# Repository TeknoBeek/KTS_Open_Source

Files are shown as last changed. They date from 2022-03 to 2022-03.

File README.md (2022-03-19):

# KTS_Open_Source

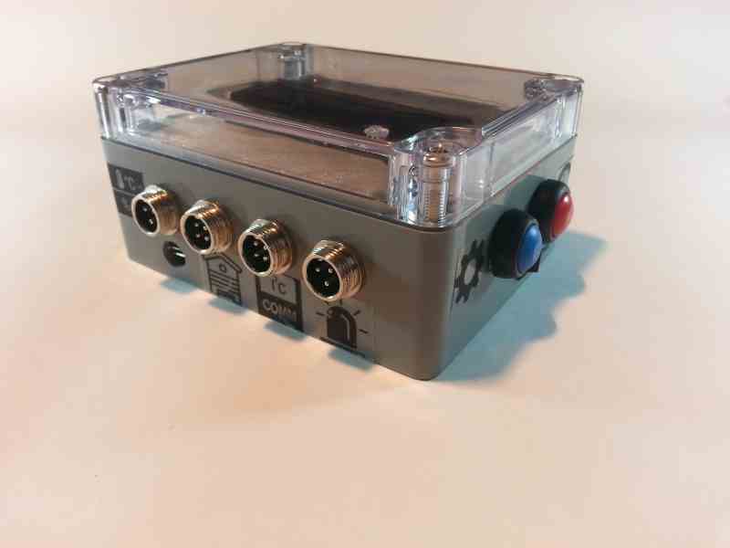
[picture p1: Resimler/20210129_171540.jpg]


# Kovan Takip Sistemi Açık Kaynak Dosyaları

KTS donanım olarak açık kaynak olarak paylaşılmıştır.

Yazılım kısmında ise cihazın TEMEL ÖZELLİKLERİNİ kullanabileceğiniz bir bedava bir sürüm (firmware) bulunmaktadır.

Profesyonel ve TAM SÜRÜME ileride küçük bir ücret mukabili geçilebilecektir.

KTS piyasada hazır olarak kolayca bulunabilecek modüller kullanılarak geliştirildi. 

Yani sonuçta AMATÖR bir cihaz olacak.

Bu yüzden de TR'de ve dünyada muhtemelen en ucuza mal edilebilecek bir veri kaydedici olacaktır.

AMATÖR bir cihaz olmasına rağmen kullanılacak alan için profesyonele yakın bir çözüm sunmaktadır. 

Ve 5 yıla aşkın saha kullanımında da gayet yeterli olduğunu kanıtlamıştır.

Bu cihazın amatör şartlar dahilinde geliştirildiğini unutmamanızı tavsiye ederim.

Bu yüzden doğabilecek olumsuzluklar hakkında hiç bir şekilde sorumluluk almam. 

Yalnız cihazın ARICILIK ile ilgili bölümündeki tasarım, 20 seneyi aşkın arıcılık geçmişim sayesinde olmuştur.

Hangi sensörlerin kullanılması gerekliliği, nerede kullanılacağı,

nelerin takip edileceği, verilerin nasıl analiz edileceği vb. konular bu sebeple yabancısı olmadığım konular.

6 seneyi aşkın bir süre içinde gelişe gelişe cihaz bugünkü haline evrildi.

KTS nedir tanıtım PDF'inde de bahsedildiği gibi bu cihaz aslında bir veri toplayıcı. 

Arıcılık sektöründe kullanılabileceği gibi SERACILIK, SULAMA, KÜMES OTOMASYONU, EV OTOMASYONU, HAVA İSTASYONU vb. 

bir çok alanda da kullanılabilecek şekilde, modüler bir biçimde yapıldı.

Farklı bir alanda kullanmak için ilgili modülü konnektörden ekleyip, o modulün

yazılımını yüklemek yeterli olacak.

Bundan sonraki tüm yazılımlar bu donanım ile uyumlu olacak.

İlerleyen zamanlarda www.akıllıkovan.com veya GitHub üzerinden bu yazılımlara ulaşmak mümkün olacak.

# NASIL BİR YOL İZLENECEK

Öncelikle www.akıllıkovan.com web sitesi dökümantasyon için kullanılacak.

GitHub adresinde de yine yapım bilgilerini içeren PDF dosyaları, PCB dosyaları (Gerber ve BRD) , ve YAZILIM Firmware bulunacak.

Youtube kanalında ise hem tanıtım videoları hem de yapım aşamalarını gösteren kısa ve uzun videolar bulanacak. Bu sebeple kanala abone olmanızı tavsiye ederim. https://www.youtube.com/c/TeknoBeek

------------------------------------------------------------------------------------

# KİMLER YAPABİLİR ?

Temel seviyede elektronik bilgisi olan herkes yapabilir.

Bilinmesi gereken konular;

Kart dizilimi ve lehimleme, (kablo lehimleme - bağlama vb. dahil)

PCB'yi kendi yapacaksa ev yapımı PCB bilgisine haiz olmak,

Mikroişlemciye yazılım atmak.

Montaj konusundaki delme, yapıştırma vb. el işçiliği.

Arıcılar yarı marangoz olduğu için en kolay kısım burası olacaktır.

Kendiniz yapamadığınız takdirde meslek lisesinde bulunan bir çocuk bile muhtemelen bunları yapabilecektir.

-------------------------------------------------------------------------------------

# PARÇALAR NEREDEN TEMİN EDİLECEK ?

Elektronik parçaların hepsi ister yurtiçinden isten yurtdışından kolaylıkla bulunabilecek şekilde tasarlandı.

Türkiye'de online alışveriş yapılabilen büyük firmaların birisinden hepsi temin edilebilir.

Elektronik kısmına ait liste sitede bulunmaktadır.

Kutu seçimi isteğe bağlı olmakla beraber açık kaynaktaki kutu TR'deki bir firmadan temin edilebilir.

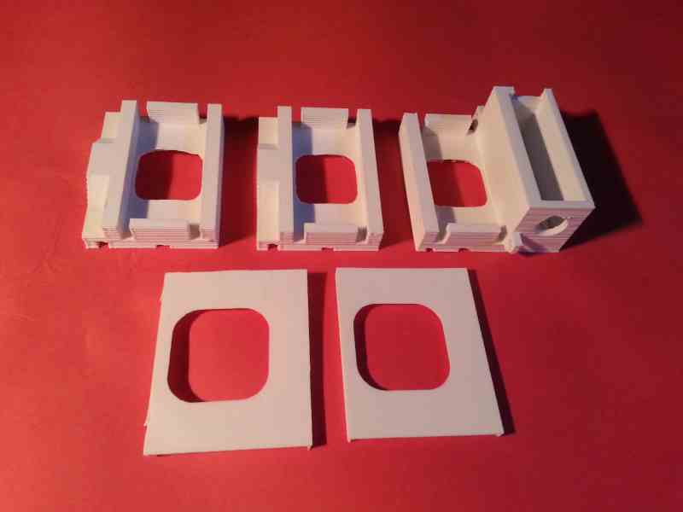
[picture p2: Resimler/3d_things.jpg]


Plastik parçalar özel üretim olduğu için muhtemelen bu projenin en zor bulunacak bölümünü oluşturuyor.

3D çizim dosyaları thingiverse hesabımdan indirilip 3D yazıcıda yazdırılabilir.

Bu hesapta da 3D klasöründe STL dosyaları bulunmaktadır.

Baskı almak için Türkiye'de 3D baskı yapan firmalar var.

Bu konuda ben de yardımcı olmaya çalışırım.

PCB konusunda kendi yapabilecek veya birine yaptırabilecek kimseler için çizim dosyaları bu hesapta bulunacaktır.

Profesyonel firma üretimi olan PCB'ler (Çin) elimde fazla bulunduğu takdirde

bu konuda da yardımcı olabilirim.

Plastik Altlık kullanılacak ise kullanılacak altlığın modeli sitede yazmaktadır.

Tüm 3D plastik parçalar bu model altlığa göredir.

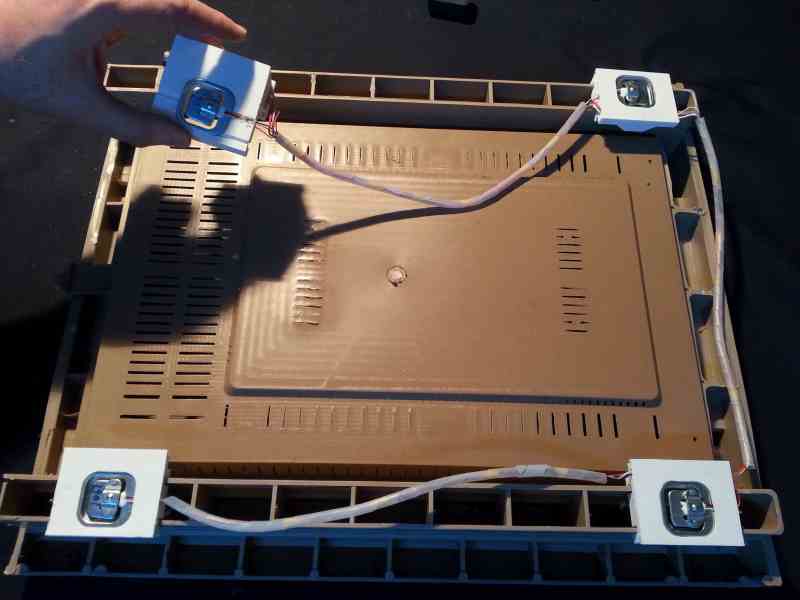
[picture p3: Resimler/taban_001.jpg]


Altlık kullanılmayıp onun yerine bir platform kullanılacaksa bununla ilgili de 3D çizimler ayrıca verilmiştir.

Piyasadan hazır dijital kantar kullanımı ile ilgili bilgi notu yakında paylaşılacaktır.

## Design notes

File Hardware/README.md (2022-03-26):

# KTS PCB 

Güncelleme: 
V_002 yüklendi. SE-222 Kodlu kutuya uygun olarak dizayn edildi. 
V_002 klasöründe gerber dosyaları mevcut. Testleri yapıldı
-------------------------------------------------------------
Önemli not ! 

Donanım ve yazılım konusunda formal bir eğitimim yoktur. 
Hobi amaçlı ve amatör ruhla geliştirilmeye çalışılmıştır. 
Bunun göz önünde tutulması rica olunur. 

Versiyon1 evde de imal edilebilmesi amacıyla ağırlıklı olarak tek yüzlü olarak tasarlandı. 
Sadece birkaç köprü kablo ile çalıştırılabilmektedir. 
Ütü, aseton vb. ev tipi tekniklerle imal edilebilir. 
Ev tipi üretim konusunda yönlendirme yapabilirim. 

Çin'den veya TR'deki bir firma üzerinden üretim yaptırmak isterseniz 
gerekli gerber dosyaları da buradadır. 
Ben bu dosyalar ile Çin üzerinden bir firma ile PCB yaptırdım. 
Elimde fazla olduğu takdirde PCB temini konusunda da yardımcı olabilirim. 

Bu dizindeki BOM dosyası Eagle CAM'in kendi çıkardığı dosyadır. 
Daha detaylı bilgiye PDF dizinindeki malzemeler dosyasından ulaşabilirsiniz.

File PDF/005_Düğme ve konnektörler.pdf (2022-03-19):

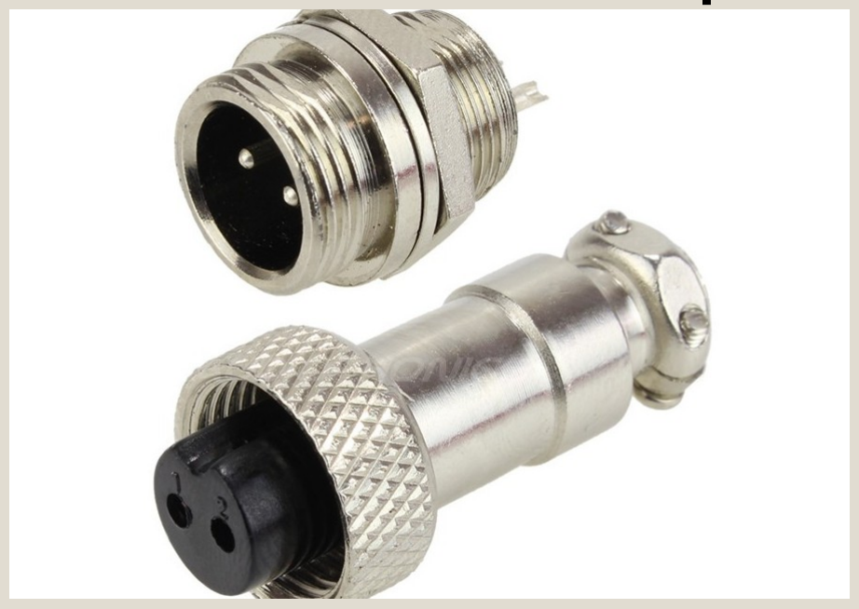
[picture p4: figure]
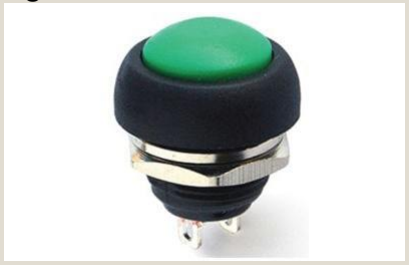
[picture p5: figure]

Konnektör olarak Gx_12 / 3 ve 4 pinli kullanıldı. Düğme olarak M12 boyutlu istenilen tip bir düğme kullanılabilir.

## Düğme ve Konnektörler

### 4 pinli bağlantı için ayak

numaraları bu şekilde
olmalı.

### 3 pinli bağlantı için ayak

numaraları bu şekilde
olmalı.

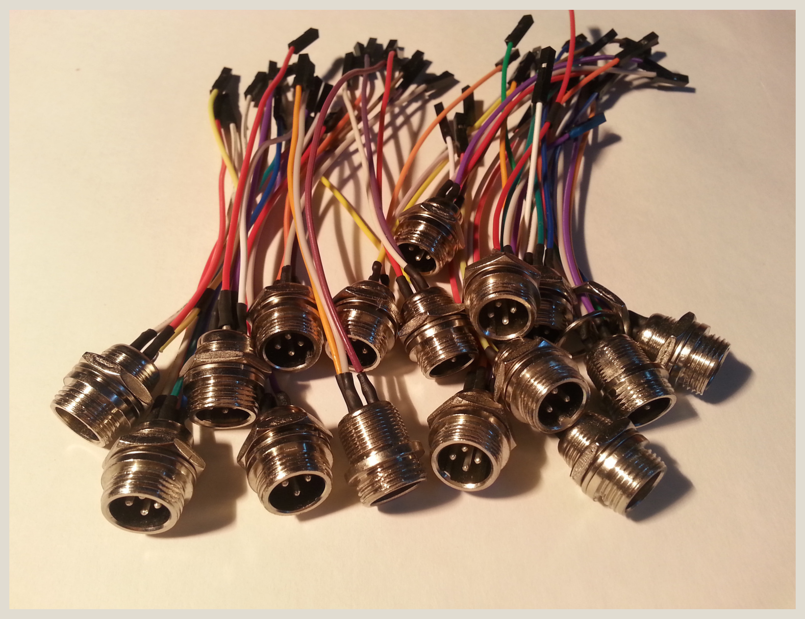
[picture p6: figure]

Kablo olarak dişi jumper
kablosu kullanılıyor.
Dişi - Dişi bir jumper
kablosunu ortadan
keserek kullanıyoruz.

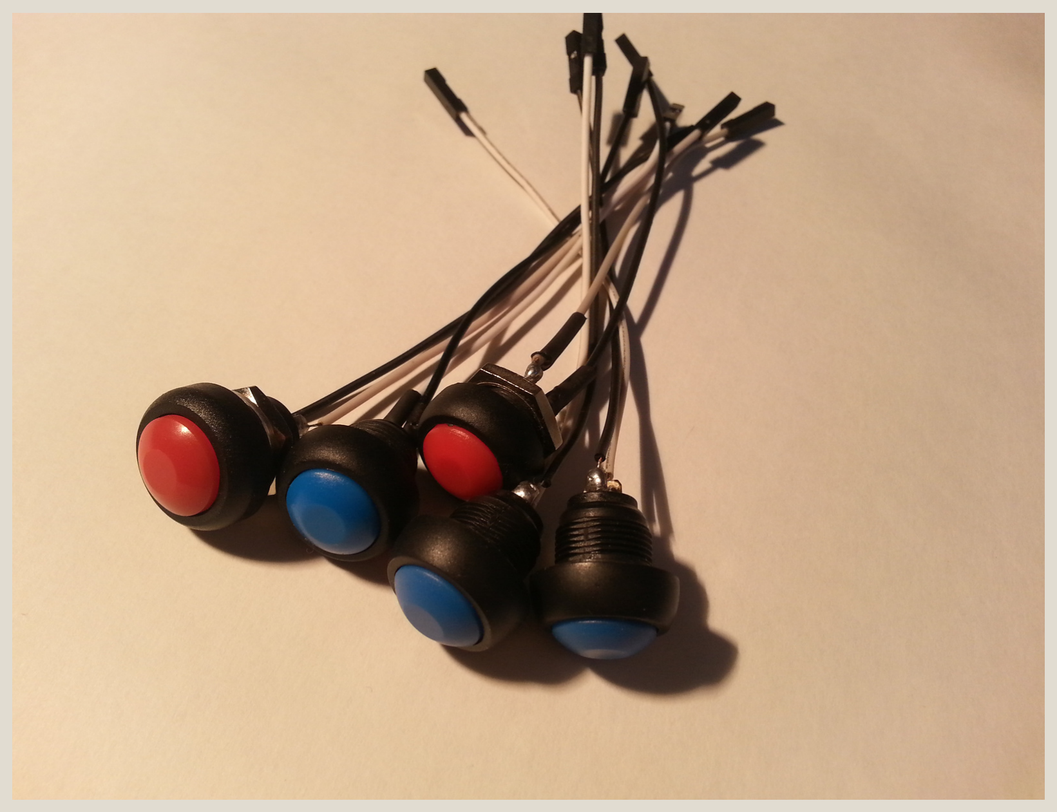
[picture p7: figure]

Vcc bağlantısı için
genelde turuncu veya
kırmızıyı, Gnd için ise
beyaz veya ona yakın
açık renkler tercih
edildi.

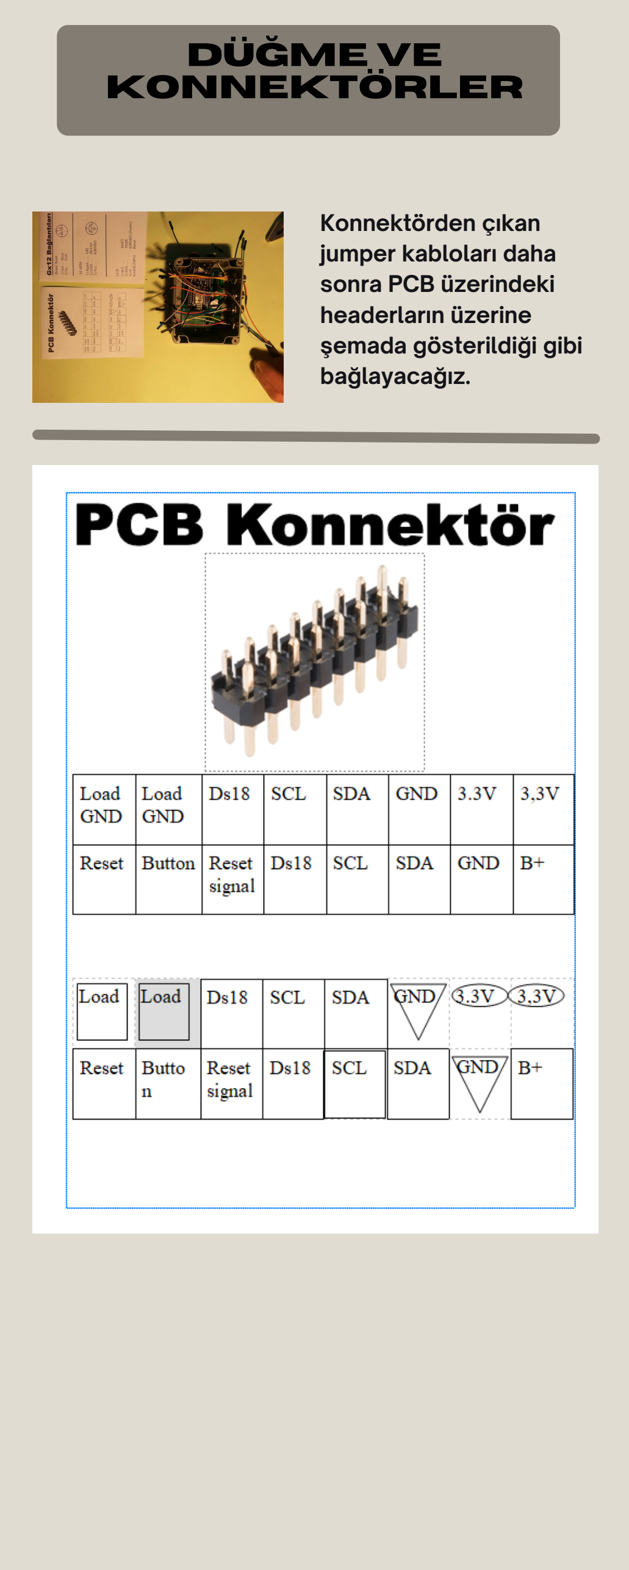
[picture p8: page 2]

Konnektörden çıkan
jumper kabloları daha
sonra PCB üzerindeki
headerların üzerine
şemada gösterildiği gibi
bağlayacağız.

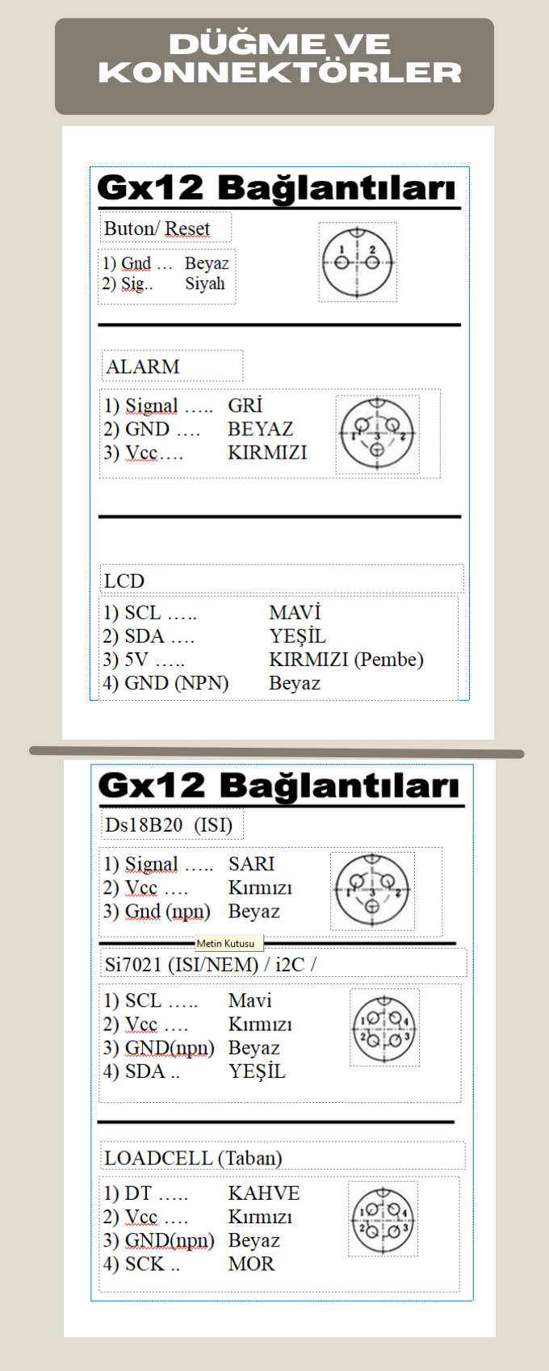
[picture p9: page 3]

## NOTLAR

1) Renkler konusunda dikkat edilecek husus; Vcc için kırmızı veya ona yakın renklerin, GND için beyaz veya yakın renklerin tercihi hata ayıklamada fayda sağlar. Onun dışında elinizde bulunan jumper kablolarının rengine göre bağlantıyı dilediğiniz gibi yapabilirsiniz. Şemada yazan renklere bağlı kalmak zorunda değilsiniz.
2) Hem konnektör hem de button ayaklarında ısı ile daralan makaron kullanılması tavsiye olunur.
3) Kutu tercihlerinize göre Gx12 yerine Gx16 konnektör veya farklı tipte düğme tercih edebilirsiniz.
Bu durumda haliyle sitedeki kutu şablonlarından istifade edemezsiniz.
4) Dişi jumper kablolar daha sonra PCB montaj bölümünde anlatılacak olan PCB üzerindeki header'a bağlanacak. Bağlantı şeması da o bölümde detaylı bir anlatımla verilecektir.
5) Cihazı full olarak kullanmak istediğiniz takdirde
3 adet erkek 4 pinli
2 adet erkek 3 pinli
3 adet dişi 4 pinli
2 adet dişi 3 pinli Gx12 konnektöre ihtiyacınız olacak.

Button olarak 2 adet push button switch yeterli.

Bu listeler başka bir bölümde (malzeme listesi) detaylı olarak ele alınacaktır.

6) Gx12 konnektörlerin hem dişi, hem erkeklerinde pinleri belirten sayılar vardır. Zaten bağlantılar bu rakamlara göre yapılacaktır.
7) LCD kablosu için birşey yapılması gerekmiyor.
Dişi - dişi 4 adet jumper kablosu yeterli. LCD'ye gelen tarafına dilerseniz bir makaron takılabilir.

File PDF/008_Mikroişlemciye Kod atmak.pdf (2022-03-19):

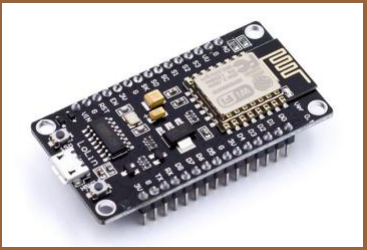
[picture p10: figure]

Piyasada iki çeşit NodeMcu var.
Bir tanesi USB için CP2102 kullanıyor. Diğeri ise Ch340.
Her ikisi için de PC'ye driver indirmeniz gerekiyor.

CP2102 chip için driver adresi: https://www.silabs.com/developers/usb-touart-bridge-vcp-drivers (https://www.silabs.com/developers/usb-to-uart-bridge-vcp-drivers)

Ch340 için driver:
https://learn.sparkfun.com/tutorials/how-to-install-ch340-drivers/all (https://learn.sparkfun.com/tutorials/how-to-install-ch340-drivers/all)

### Mikroişlemciye YAZILIM YÜKLEME

ANA İŞLEMCİ
--------------------------------NodeMCU LoLin
ESP8266 Geliştirme
Kartı - USB Chip (https://www.motorobit.com/urun/nodemcu-lolin-esp8266-gelistirme-karti-usb-chip)

Driverlar işletim sisteminize sorunsuz bir şekilde tanıtıldıktan sonra artık USB kablosu ile PC'nizin USB'sine mikroişlemcimizi bağlayabilir ve yazılım atabiliriz.
Yazılım atabilmek için bir programa ihtiyaç var. Piyasada çok program olsa da benim tercihim şu:
Win32 (https://github.com/nodemcu/nodemcu-flasher/raw/master/Win32/Release/ESP8266Flasher.exe)
Win64 (https://github.com/nodemcu/nodemcu-flasher/raw/master/Win64/Release/ESP8266Flasher.exe)

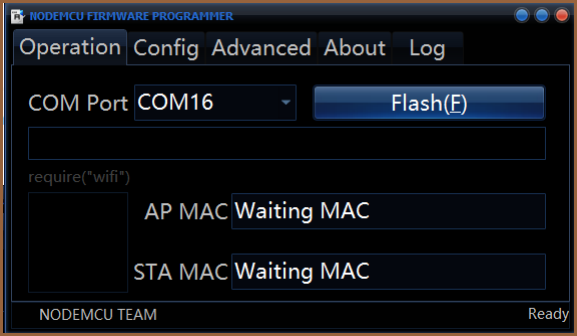
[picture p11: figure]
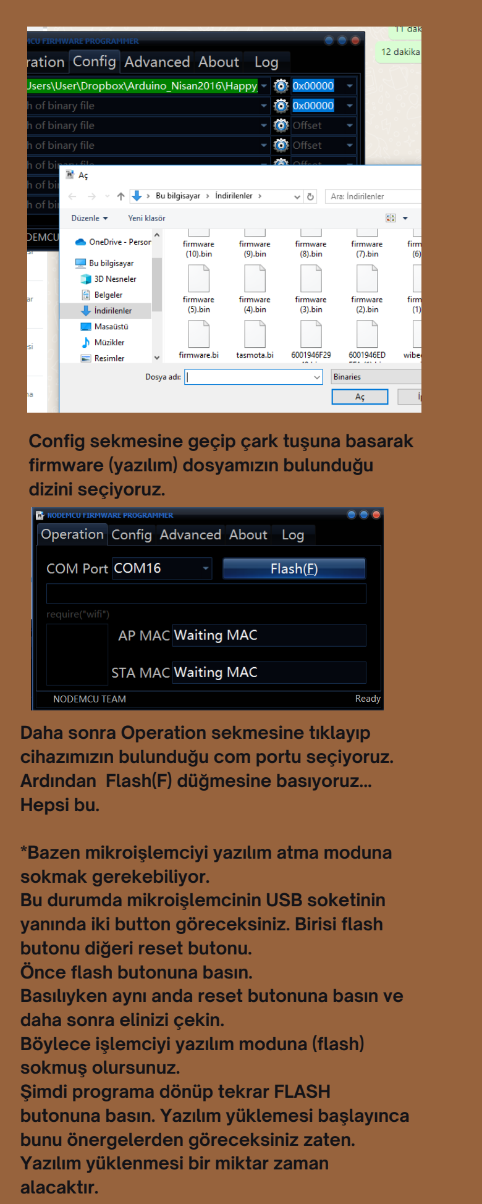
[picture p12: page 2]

Config sekmesine geçip çark tuşuna basarak firmware (yazılım) dosyamızın bulunduğu dizini seçiyoruz.

Daha sonra Operation sekmesine tıklayıp cihazımızın bulunduğu com portu seçiyoruz. Ardından Flash(F) düğmesine basıyoruz... Hepsi bu.

*Bazen mikroişlemciyi yazılım atma moduna sokmak gerekebiliyor.
Bu durumda mikroişlemcinin USB soketinin yanında iki button göreceksiniz. Birisi flash butonu diğeri reset butonu.
Önce flash butonuna basın.
Basılıyken aynı anda reset butonuna basın ve daha sonra elinizi çekin.
Böylece işlemciyi yazılım moduna (flash) sokmuş olursunuz.
Şimdi programa dönüp tekrar FLASH butonuna basın. Yazılım yüklemesi başlayınca bunu önergelerden göreceksiniz zaten. Yazılım yüklenmesi bir miktar zaman alacaktır.

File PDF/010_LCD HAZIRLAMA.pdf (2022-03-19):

### LCD HAZIRLAMA

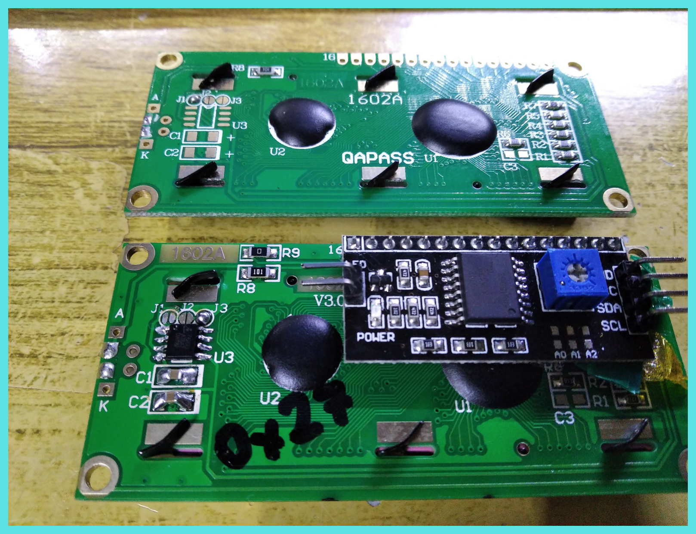
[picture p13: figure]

Bu ekranlar normalde
5V olduğu için bunu
3.3V'a çevirmemiz
gerekiyor.

Bunun için 2 adet 10uf
kapasitör (SMD) ve bir
adet L7660 SMD DC DC
çevirici kullanmak
gerekiyor.

En son mevcut jumper
lehimini söküp en sağdaki
yeri lehimlemeliyiz.

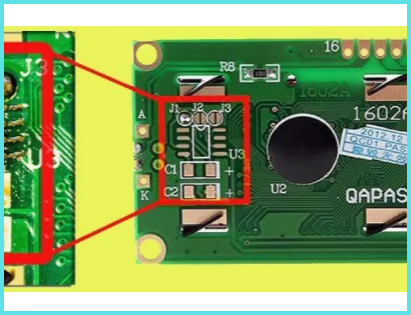
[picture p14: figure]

Detaylı bilgiye buradan (https://www.codrey.com/electronic-circuits/hack-your-16x2-lcd/)
ulaşabilirsiniz...

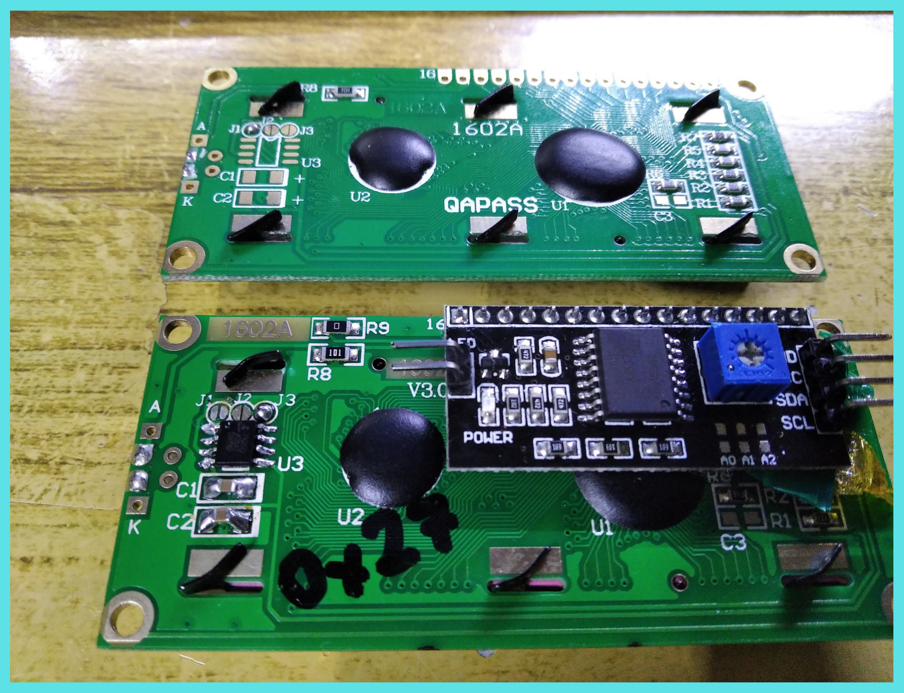
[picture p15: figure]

16x2 Standart bir
ekrana i2c modülü
takıyoruz

Standart bir 5V 16x2 LCD ekranı

### 3.3 V'a çevirmek

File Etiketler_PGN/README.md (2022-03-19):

# Etiketler



Kutu üzerinde kullanılacak etiketler 

ve kutu yapımında kullanılacak şablon -  bağlantı şemaları vb. dökümasyona buradan ulaşabilirsiniz.

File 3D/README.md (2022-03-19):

# 3D Dosyalar



Bu parçalar TR'de satılan bir plastik kovana uyumlu yapılmıştır. 

Başka bir altlık ile uyumsuzluk yaşanması muhtemeldir. 

Plastik altlık yerine düz bir platforma uygulama yapılacaksa bunun için 

https://www.thingiverse.com/search?q=loadcell&type=things&sort=relevant üzerinden bir aratma yapılıp 

size uygun tasarıp bulunup basılabilir. 

Buradaki dosyalar https://www.thingiverse.com/cemoka/designs hesabımda da bulunmaktadır. 

Oradan her zaman daha güncel dosyalara erişmek mümkün olacaktır. 

PetG veya ABS gibi dayanıklı bir malzeme ile baskı tercih edilmelidir.

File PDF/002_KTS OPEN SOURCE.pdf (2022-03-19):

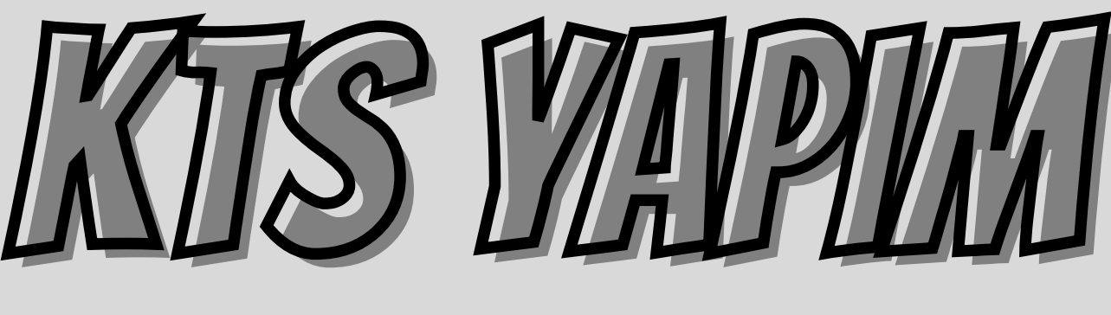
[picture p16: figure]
KTS YAPIM
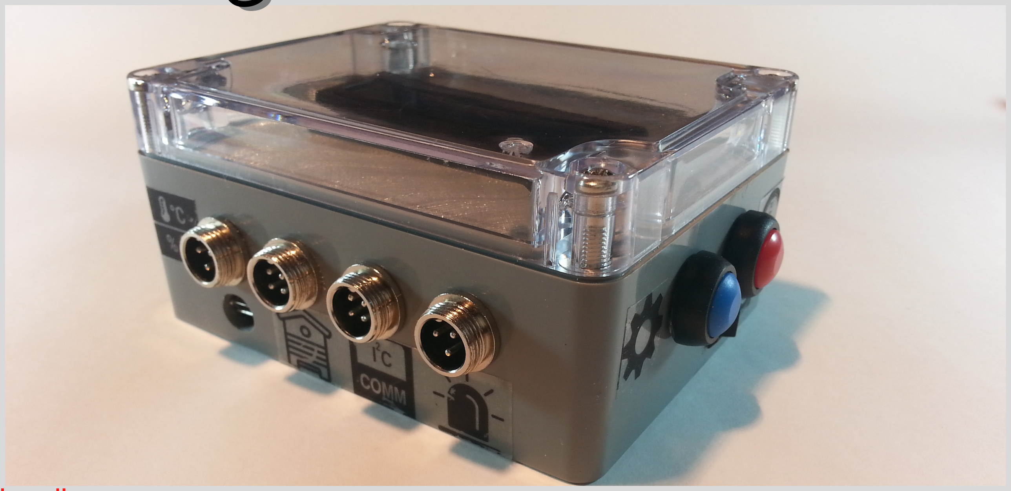
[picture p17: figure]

ÖNSÖZ
KTS donanım olarak açık kaynak paylaşılmıştır.
Yazılım kısmında ise cihazın TEMEL ÖZELLİKLERİNİ kullanabileceğiniz bir bedava bir sürüm (firmware) bulunmaktadır.
Profesyonel ve TAM SÜRÜME ileride küçük bir ücret mukabili geçilebilecektir.

KTS piyasada hazır olarak kolayca bulunabilecek modüller kullanılarak geliştirildi. Yani sonuçta AMATÖR bir cihaz olacak.
Bu yüzden de TR'de ve dünyada muhtemelen en ucuza mal edilebilecek bir veri kaydedici olacaktır.
AMATÖR bir cihaz olmasına rağmen kullanılacak alan için profesyonele yakın bir çözüm sunmaktadır. Ve 5 yıla aşkın saha kullanımında da gayet yeterli olduğunu kanıtlamıştır.

Biraz da proje geliştiricisi bendeniz hakkında konuşayım:
Ben çocukluktan beri elektroniği hobi amaçlı ve amatör düzeyde yapmaktayım. Gerek donanım gerekse yazılım konusunda formal bir eğitimim olmadı.
Bu konuda kendi kendimi yetiştirdim.
Fakat yine de her iki alanda da çok yetersiz olduğum bir gerçek.
Bu cihazın bu şartlar dahilinde geliştirildiğini unutmamanızı tavsiye ederim. Bu yüzden doğabilecek olumsuzluklar hakkında hiç bir şekilde sorumluluk almam. Yalnız cihazın ARICILIK ile ilgili bölümündeki tasarım, 20 seneyi aşkın arıcılık geçmişim sayesinde olmuştur.
Hangi sensörlerin kullanılması gerekliliği, nerede kullanılacağı,
nelerin takip edileceği, verilerin nasıl analiz edileceği vb. konular bu sebeple yabancısı olmadığım konular.
6 seneyi aşkın bir süre içinde gelişe gelişe cihaz bugünkü haline evrildi.

Takip edenlerin bileceği gibi kovan verilerinin takip edilebileceği bir profesyonel cihaz geçen yıllar içinde üretildi.
Ancak firma ile olan anlaşmazlıklar sebebiyle (özellikle fiyat konusunda) cihazı onlara bırakıp o süreçten çekildim ve yine eski kendi cihazıma döndüm.
Yani hazır modüller kullanılarak oluşturulan bir donanım ve yazılım ile bu cihaz hazırlandı.

KTS nedir tanıtım PDF'inde de bahsedildiği gibi bu cihaz aslında bir veri toplayıcı. Arıcılık sektöründe kullanılabileceği gibi SERACILIK, SULAMA, KÜMES OTOMASYONU, EV OTOMASYONU, HAVA İSTASYONU vb. bir çok alanda da kullanılabilecek şekilde, modüler bir biçimde yapıldı.

Farklı bir alanda kullanmak için ilgili modülü konnektörden ekleyip, o modulün yazılımını yüklemek yeterli olacak.

Bundan sonraki tüm yazılımlar bu donanım ile uyumlu olacak.
İlerleyen zamanlarda www.akıllıkovan.com (https://www.xn--akllkovan-wpbc.com/p/kts-nedir.html) veya GitHub (https://github.com/TeknoBeek) hesabı üzerinden bu yazılımlara ulaşmak mümkün olacak.

# AÇIK KAYNAK

NASIL BİR YOL İZLENECEK

Öncelikle www.akıllıkovan.com (https://www.xn--akllkovan-wpbc.com/p/kts-nedir.html) web sitesi dökümantasyon için kullanılacak.

GitHub (https://github.com/TeknoBeek) adresinde de yine yapım bilgilerini içeren PDF dosyaları, PCB dosyaları (Gerber ve BRD) , ve YAZILIM Firmware bulunacak.

Youtube kanalında ise hem tanıtım videoları hem de yapım aşamalarını gösteren kısa ve uzun videolar bulanacak. Bu sebeple kanala abone olmanızı tavsiye ederim. https://www.youtube.com/c/TeknoBeek

---------------------------------------------------------------------------------------------------------------KİMLER YAPABİLİR ?

Temel seviyede elektronik bilgisi olan herkes yapabilir.
Bilinmesi gereken konular;

Kart dizilimi ve lehimleme, (kablo lehimleme - bağlama vb. dahil) PCB'yi kendi yapacaksa ev yapımı PCB bilgisine haiz olmak, Mikroişlemciye yazılım atmak.
Montaj konusundaki delme, yapıştırma vb. el işçiliği.
Arıcılar yarı marangoz olduğu için en kolay kısım burası olacaktır.

Kendiniz yapamadığınız takdirde meslek lisesinde bulunan bir çocuk bile muhtemelen bunları yapabilecektir. ---------------------------------------------------------------------------------------------------------------PARÇALAR NEREDEN TEMİN EDİLECEK ?

Elektronik parçaların hepsi ister yurtiçinden isten yurtdışından kolaylıkla bulunabilecek şekilde tasarlandı.
Türkiye'de online alışveriş yapılabilen büyük firmaların birisinden hepsi temin edilebilir.
Elektronik kısmına ait liste sitede bulunmaktadır.

Yapacağınız cihazda ihtiyacınız olmayacağını düşündüğünüz sensörleri iptal edebilirsiniz. Mesela "Ben sadece ağırlık takip etmek istiyorum" diyen biri ısı ve nem sensörlerini almayabilir. Fakat sensörleri almasanız da kutudaki konnektörlerin tam olmasını tavsiye ederim.
Zira ilerideki farklı kullanım alanları için cihazınız standart donanıma sahip olmuş olur.
Mesela ileride aynı cihazı otomatik sulama veya SERA otomasyonu gibi bir amaçla da kullanabilirsiniz. Zaten konnektör farkı 10 - 15 TL gibi bir tutardır.

Kutu seçimi isteğe bağlı olmakla beraber açık kaynaktaki kutu TR'deki bir firmadan temin edilebilir.

Plastik parçalar özel üretim olduğu için muhtemelen bu projenin en zor bulunacak bölümünü oluşturuyor.
3D çizim dosyaları thingiverse (https://www.thingiverse.com/cemoka/designs) hesabımdan indirilip 3D yazıcıda yazdırılabilir. 3D baskı yapan firmalar var.
Bu konuda ben de yardımcı olmaya çalışırım.

PCB konusunda kendi yapabilecek veya birine yaptırabilecek kimseler için çizim dosyaları gitHub (https://github.com/TeknoBeek) hesabında bulunacaktır.
Profesyonel firma üretimi olan PCB'ler (Çin) elimde fazla bulunduğu takdirde bu konuda da yardımcı olabilirim.

Plastik Altlık kullanılacak ise kullanılacak altlığın modeli önemlidir.
Tüm 3D plastik parçalar bu model altlığa göredir.
Altlık kullanılmayıp onun yerine bir platform kullanılacaksa bununla ilgili de 3D çizimler ayrıca verilmiştir.

Piyasadan hazır dijital kantar kullanımı ile ilgili bilgi notu yakında paylaşılacaktır.

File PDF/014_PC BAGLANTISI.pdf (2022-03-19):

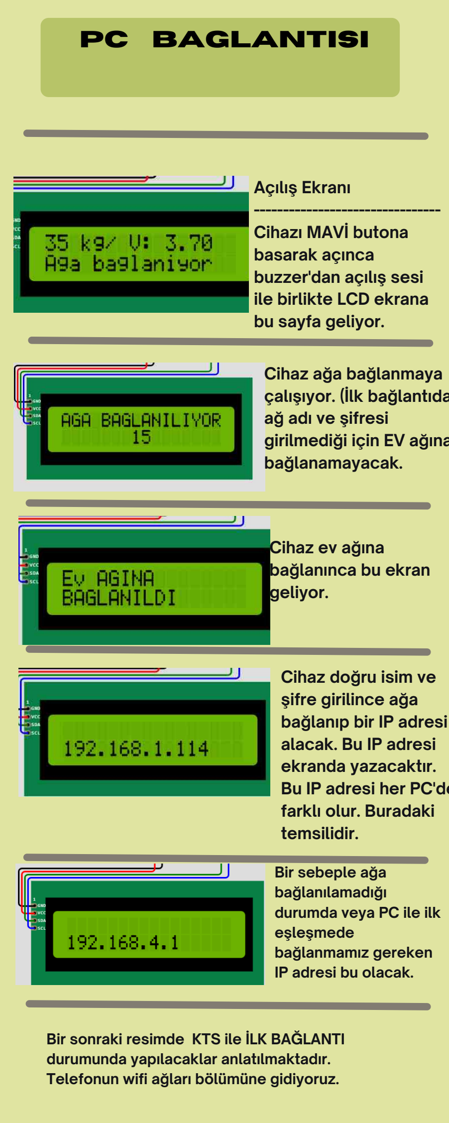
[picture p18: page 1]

Açılış Ekranı
--------------------------------Cihazı MAVİ butona
basarak açınca
buzzer'dan açılış sesi
ile birlikte LCD ekrana
bu sayfa geliyor.

Cihaz ağa bağlanmaya
çalışıyor. (İlk bağlantıda ağ adı ve şifresi
girilmediği için EV ağına
bağlanamayacak.

Cihaz ev ağına
bağlanınca bu ekran
geliyor.

Cihaz doğru isim ve
şifre girilince ağa
bağlanıp bir IP adresi
alacak. Bu IP adresi
ekranda yazacaktır.
Bu IP adresi her PC'de
farklı olur. Buradaki
temsilidir.

PC BAGLANTISI

Bir sebeple ağa
bağlanılamadığı
durumda veya PC ile ilk
eşleşmede
bağlanmamız gereken
IP adresi bu olacak.

Bir sonraki resimde KTS ile İLK BAĞLANTI durumunda yapılacaklar anlatılmaktadır. Telefonun wifi ağları bölümüne gidiyoruz.

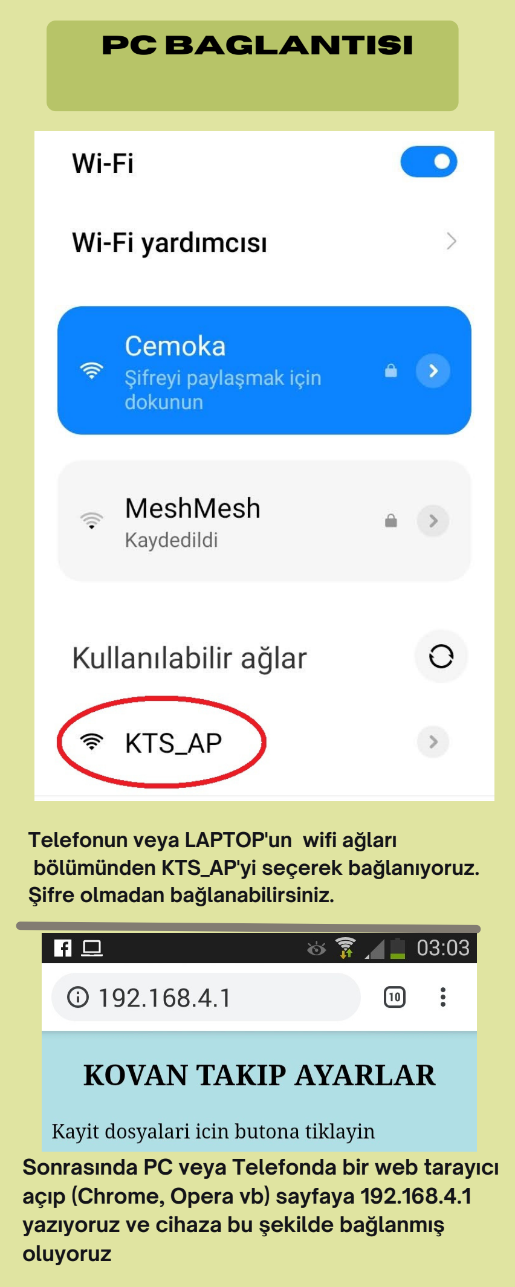
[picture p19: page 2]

Telefonun veya LAPTOP'un wifi ağları bölümünden KTS_AP'yi seçerek bağlanıyoruz. Şifre olmadan bağlanabilirsiniz.

Sonrasında PC veya Telefonda bir web tarayıcı açıp (Chrome, Opera vb) sayfaya 192.168.4.1 yazıyoruz ve cihaza bu şekilde bağlanmış oluyoruz

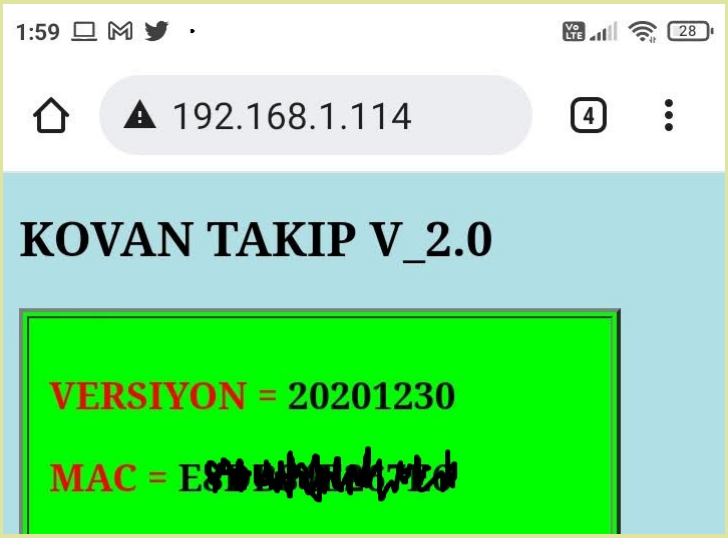
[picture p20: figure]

Cihaza daha önce sizin ev ağınızın ADI ve ŞİFRESİ girilmişse bu durumda cihazın ekranında yazan IP web tarayıcısına yazılacaktır.
Ev ağını bağlı olacağınız için bu durumda WIFI üzerinden KTS_AP'yi seçmeniz gerekmeyecektir.

Direk olarak 192.168.1.114 (sizin ağınızdan verilen IP farklı olacaktır) web tarayıcısı üzerinde yazılarak cihaza bağlanılabilir.

Ağa bağlanılamayan durumlarda (veya PC ile ilk bağlantıda)
1) KTS_AP'ye bağlanılacak.
2) Web tarayıcıya 192.168.4.1 yazılacak.

Ağa bağlanıldığı durumlarda, web tarayıcısına LCD ekranda size verilen IP yazılacak.
Başka bir işleme gerek yok.

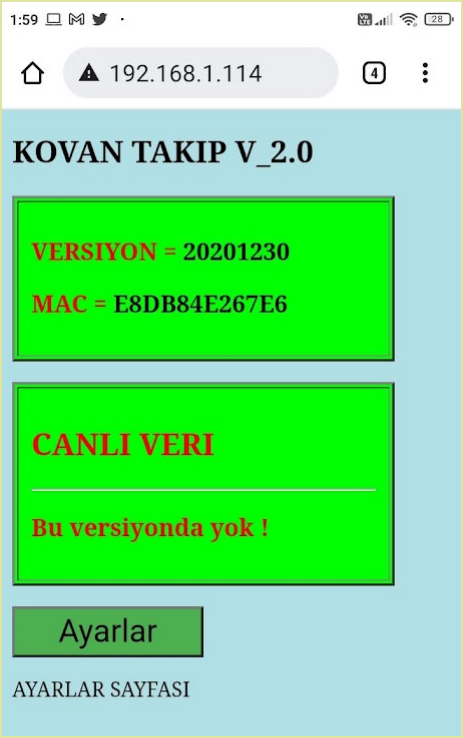
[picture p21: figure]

Versiyon: Cihazdaki son yazılım versiyonu

MAC: Cihazın ağ üzerindeki MAC ID'si. Bu numarayı kaydedin. PRO Sürüme geçerseniz bu MAC'e ihtiyaç olacaktır.

CANLI VERİ: DEMO versiyonunda bu gösterilmiyor

AYARLAR: Bu butona basarak AYARLAR sayfasına geçebilirsiniz.

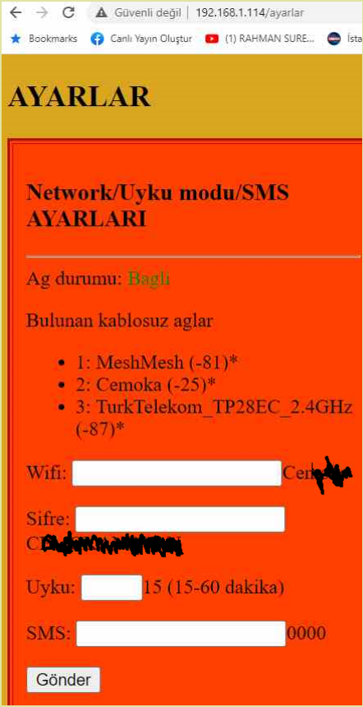
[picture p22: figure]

Wifi: Cihazın bağlanacağı ağın ismi. (girdi alanının yanında mevcut isim yazılıdır)

Şifre: Cihazın bağlanacağı ağın şifresi . (girdi alanının yanında mevcut şifre yazılıdır)

UYKU: Cihazın ölçüm yapma aralığı. (Dakika cinsinden)

SMS: Bu versiyonda çalışmıyor.

ÖNEMLİ NOT ! : Değişiklik yapıldığı zaman mutlaka gönder butonuna basarak sayfanın yenilenmesi gerekmektedir.
Aksi takdirde değişiklikler kaydedilmez. Değişiklik olup sayfa yenilendiğinde kutuların yanındaki bilgilerin değiştiğini göreceksiniz.

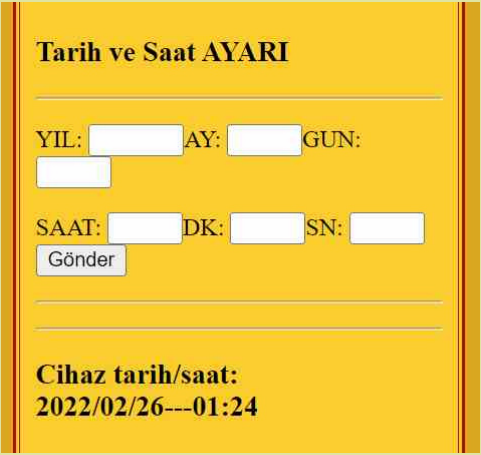
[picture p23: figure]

TARİH ve SAAT AYARI:
İlk ayarlamada cihazın tarihini 2000'li bir rakam olarak görebilirsiniz.
Tarih ve Saat ayarını bir kere yaptığınız takdirde yıllarca tekrar ayarlamak gerekmez.
PRO versiyonda internet tabanlı saat ayarı da bulunmaktadır.
Yıl - ay - gün / Saat - Dakika - Saniye verilerini başında sıfır olarak giren.
Örnek: 2022 / 03 / 03 gibi....
Veya 05 / 06 / 00 gibi.
Bilgiler girildikten sonra en son
yine GÖNDER butonuna basmayı unutmayın. Herşey doğru yapıldıysa Cihaz tarih ve saatinin değiştiğini göreceksiniz.

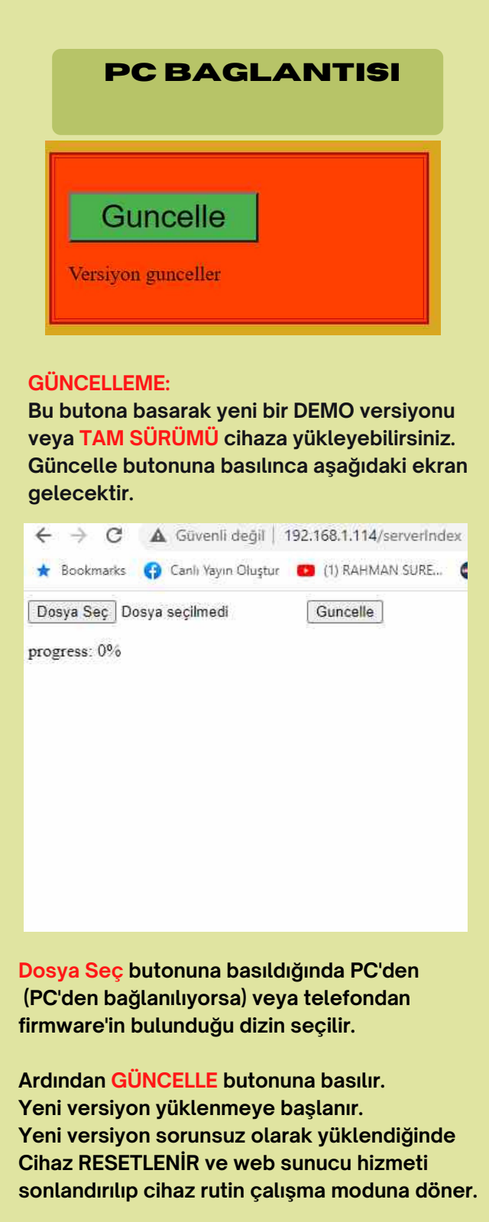
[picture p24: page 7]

GÜNCELLEME:
Bu butona basarak yeni bir DEMO versiyonu veya TAM SÜRÜMÜ cihaza yükleyebilirsiniz. Güncelle butonuna basılınca aşağıdaki ekran gelecektir.

Dosya Seç butonuna basıldığında PC'den (PC'den bağlanılıyorsa) veya telefondan firmware'in bulunduğu dizin seçilir.

Ardından GÜNCELLE butonuna basılır.
Yeni versiyon yüklenmeye başlanır.
Yeni versiyon sorunsuz olarak yüklendiğinde Cihaz RESETLENİR ve web sunucu hizmeti sonlandırılıp cihaz rutin çalışma moduna döner.

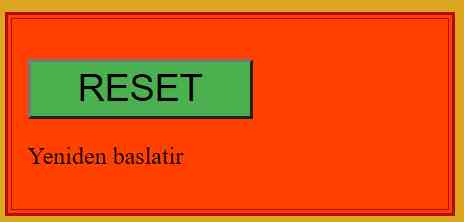
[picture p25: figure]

RESET:
Basıldığı takdirde web sunucusundan çıkılır ve cihaz RESETLENEREK rutin çalışma moduna geri döner.

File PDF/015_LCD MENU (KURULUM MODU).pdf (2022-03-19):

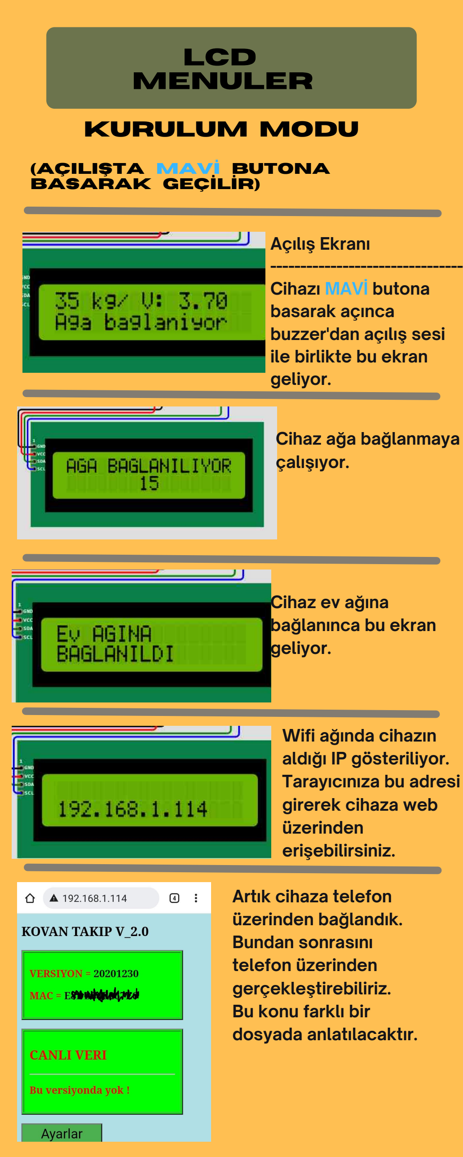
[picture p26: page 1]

### LCD MENULER

Açılış Ekranı
--------------------------------Cihazı MAVİ butona
basarak açınca
buzzer'dan açılış sesi
ile birlikte bu ekran
geliyor.

KURULUM MODU

(açılışta MAVİ butona
basarak geçİlİr)

Cihaz ağa bağlanmaya
çalışıyor.

Cihaz ev ağına
bağlanınca bu ekran
geliyor.

Wifi ağında cihazın
aldığı IP gösteriliyor.
Tarayıcınıza bu adresi
girerek cihaza web
üzerinden
erişebilirsiniz.

Artık cihaza telefon
üzerinden bağlandık.
Bundan sonrasını
telefon üzerinden
gerçekleştirebiliriz.
Bu konu farklı bir
dosyada anlatılacaktır.

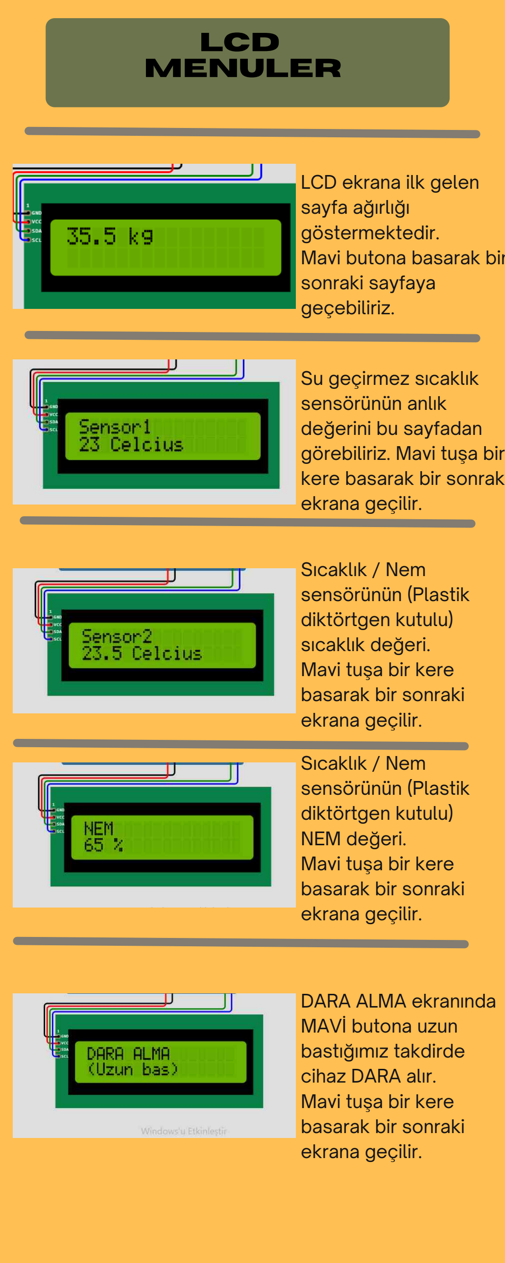
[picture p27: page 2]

LCD ekrana ilk gelen
sayfa ağırlığı
göstermektedir.
Mavi butona basarak bin
sonraki sayfaya
geçebiliriz.

Su geçirmez sıcaklık
sensörünün anlık
değerini bu sayfadan
görebiliriz. Mavi tuşa bir kere basarak bir sonrak
ekrana geçilir.

Sıcaklık / Nem
sensörünün (Plastik
diktörtgen kutulu)
sıcaklık değeri.
Mavi tuşa bir kere
basarak bir sonraki
ekrana geçilir.

Sıcaklık / Nem
sensörünün (Plastik
diktörtgen kutulu)
NEM değeri.
Mavi tuşa bir kere
basarak bir sonraki
ekrana geçilir.

DARA ALMA ekranında
MAVİ butona uzun
bastığımız takdirde
cihaz DARA alır.
Mavi tuşa bir kere
basarak bir sonraki
ekrana geçilir.

AYARLAR ekranında
MAVİ butona uzun
bastığımız takdirde alt
ayar menülerine erişilir.
Fakat DEMO
Sürümünde bu kısım
AKTIF değildir.
Mavi tuşa bir kere
basarak bir sonraki
ekrana geçilir.

Cihazınızın MAC ID'sini
gösterir.
Wifi ağına
bağlandığınızda bu
MAC ID ile kayıt
olursunuz. PRO sürümü
için de bu ID gereklidir.
Mavi tuşa bir kere
basarak bir sonraki
ekrana geçilir.


Bu ekrandayken MAVİ
butona UZUN basarak
cihazı RESETLERİZ.
Cihaz böylece
KURULUM modundan
çıkıp, normal rutinine
döner.

5 dakika KURULUM
modunda durduktan
sonra cihaz kendi
kendine 5'den geri
sayarak kapanır.


** Herhangi bir ekranda MAVİ butona iki kere basıldığı takdirde AĞIRLIK ekranına gidilir.

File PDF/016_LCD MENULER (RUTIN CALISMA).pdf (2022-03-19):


### LCD MENULER

Açılış Ekranı
--------------------------------Cihaz açılınca
buzzer'dan açılış sesi
ile birlikte bu ekran
geliyor.

Rutin ÇALIŞma MODU

Cihaz ağa bağlanmaya
çalışıyor.

Cihaz ev ağına
bağlanınca bu ekran
geliyor.

Herhangi bir ağa
bağlanılamadığı
takdirde cihaz çevrim
dışı olarak çalışmaya
devam ediyor.

Sunucuya bağlanarak
güncel bir yazılım olup
olmadığını kontrol
ediyor. Cihaz yazılımı
güncel ise bunu
bildiriyor değilse
güncelleme indiriliyor.

### LCD MENULER


Cihaz verileri dahili
hafızaya kaydettikten
sonra belirlenen dakika
boyunca enerji
tasarrufu sağlamak için
uykuya dalıyor.


Cihaz belirlenen süre
sonunda uyanıp tekrar
veri kaydetmek üzere
UYKU moduna geçiyor.

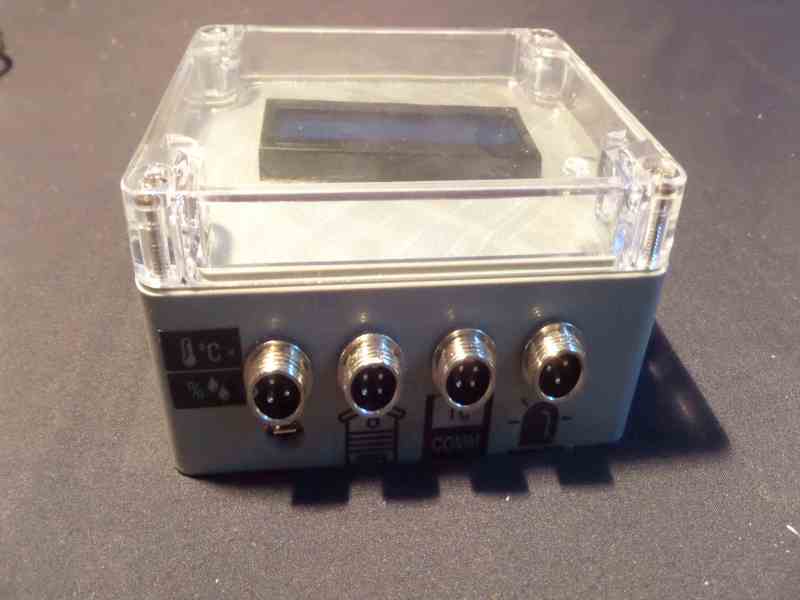
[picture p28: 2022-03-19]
Resimler/SAM_7679.jpg

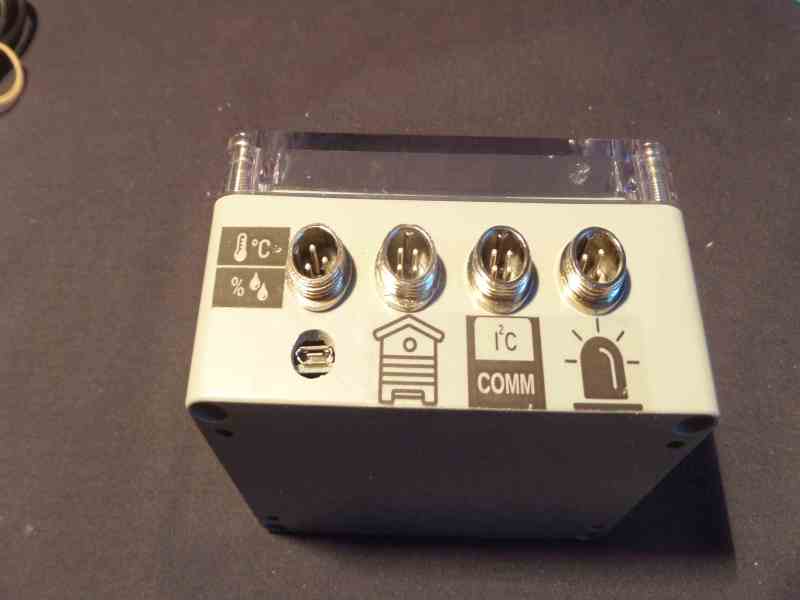
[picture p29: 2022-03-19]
Resimler/SAM_7675.jpg

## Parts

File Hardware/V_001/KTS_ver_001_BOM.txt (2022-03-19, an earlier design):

Partlist exported from C:/Users/User/Desktop/Happy_final_001.sch at 13.03.2022 03:56:31

Part        Value              Device             Package              Description                                                                                                                                                                                                                                                                                                                                                                                                                                                                                                                                                                   MF MPN OC_FARNELL OC_NEWARK PROD_ID   VALUE
B+                             M01OFFSET          1X01_OFFSET          Header 1                                                                                                                                                                                                                                                                                                                                                                                                                                                                                                                                                                                                                 
B-                             M01OFFSET          1X01_OFFSET          Header 1                                                                                                                                                                                                                                                                                                                                                                                                                                                                                                                                                                                                                 
C2                             CAP_POLPTH2        CPOL-RADIAL-10UF-25V Capacitor Polarized                                                                                                                                                                                                                                                                                                                                                                                                                                                                                                                                                                                                      
D2          1N4446             1N4446             DO35-10              DIODE                                                                                                                                                                                                                                                                                                                                                                                                                                                                                                                                                                                                                    
GND                            M01PTH             1X01                 Header 1                                                                                                                                                                                                                                                                                                                                                                                                                                                                                                                                                                                                                 
HX711_MAIN1 Hx711              M04LOCK            1X04_LOCK            Header 4                                                                                                                                                                                                                                                                                                                                                                                                                                                                                                                                                                                                                 
JP1                            M01PTH             1X01                 Header 1                                                                                                                                                                                                                                                                                                                                                                                                                                                                                                                                                                                                                 
JP2                            M01PTH             1X01                 Header 1                                                                                                                                                                                                                                                                                                                                                                                                                                                                                                                                                                                                                 
JP3                            M01PTH             1X01                 Header 1                                                                                                                                                                                                                                                                                                                                                                                                                                                                                                                                                                                                                 
Q1          2N2222             2N2222             TO18                 NPN Transistor                                                                                                                                                                                                                                                                                                                                                                                                                                                                                                                                                                                                           
Q4          2N2222             2N2222             TO18                 NPN Transistor                                                                                                                                                                                                                                                                                                                                                                                                                                                                                                                                                                                                           
R1          1K                 1KOHM-1/4W-1%(PTH) AXIAL-0.3            RES-12182                                                                                                                                                                                                                                                                                                                                                                                                                                                                                                                                                                                                 RES-12182 1K   
R2          1K                 1KOHM-1/4W-1%(PTH) AXIAL-0.3            RES-12182                                                                                                                                                                                                                                                                                                                                                                                                                                                                                                                                                                                                 RES-12182 1K   
R3          1K                 1KOHM-1/4W-1%(PTH) AXIAL-0.3            RES-12182                                                                                                                                                                                                                                                                                                                                                                                                                                                                                                                                                                                                 RES-12182 1K   
R4          1K                 1KOHM-1/4W-1%(PTH) AXIAL-0.3            RES-12182                                                                                                                                                                                                                                                                                                                                                                                                                                                                                                                                                                                                 RES-12182 1K   
SG1         F/QMBIII           F/QMBIII           F/QMBIII             BUZZER Source: Buerklin                                                                                                                                                                                                                                                                                                                                                                                                                                                                                                                                                              unknown    unknown                  
SM1                            HX711              HX711                HX711 module is a Load Cell Amplifier breakout board for the HX711 IC that allows you to easily read load cells to measure weight. This module uses 24 high precision A/D converter chip HX711. It is a specially designed for the high precision electronic scale design, with two analog input channel, the internal integration of 128 times the programmable gain amplifier. The input circuit can be configured to provide a bridge type pressure bridge (such as pressure, weighing sensor mode), is of high precision, low cost is an ideal sampling front-end module.                                            
U$3         NODEMCU            NODEMCU            NODEMCU                                                                                                                                                                                                                                                                                                                                                                                                                                                                                                                                                                                                                                       
U$4         RTC-DS3231-AT24C32 RTC-DS3231-AT24C32 RTC-DS3231-AT24C32   RTC Module with Battery and EEPROM based on DS3231 and AT24C32 chips                                                                                                                                                                                                                                                                                                                                                                                                                                                                                                                                                     
VIN                            M01PTH             1X01                 Header 1                                                                                                                                                                                                                                                                                                                                                                                                                                                                                                                                                                                                                 
VOUT                           M01PTH             1X01                 Header 1                                                                                                                                                                                                                                                                                                                                                                                                                                                                                                                                                                                                                 
X3          2516-              2516-              PAK100/2500-16       3M (TM) Pak 100 4-Wall Header                                                                                                                                                                                                                                                                                                                                                                                                                                                                                                                                                        unknown    unknown

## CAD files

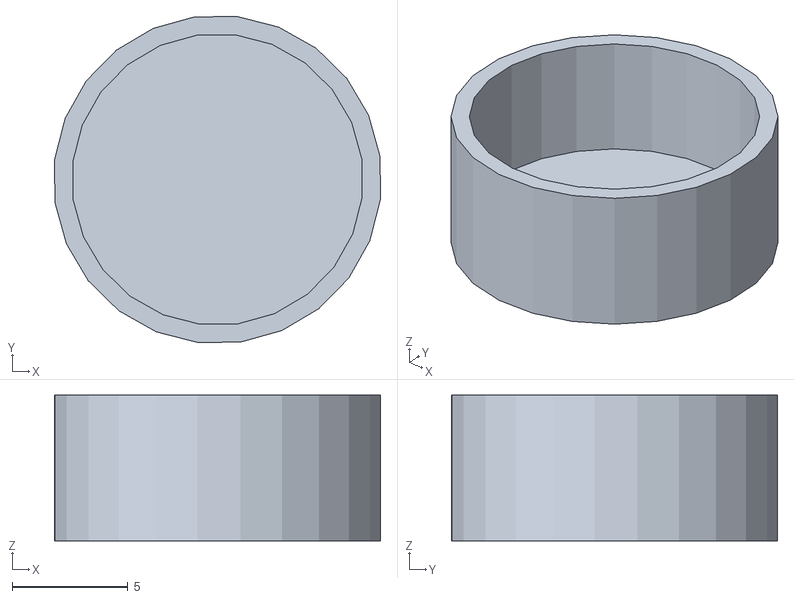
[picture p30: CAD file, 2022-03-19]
3D/KTS_Gx12_connecton_cap.stl
14.1 x 14.1 x 6.30

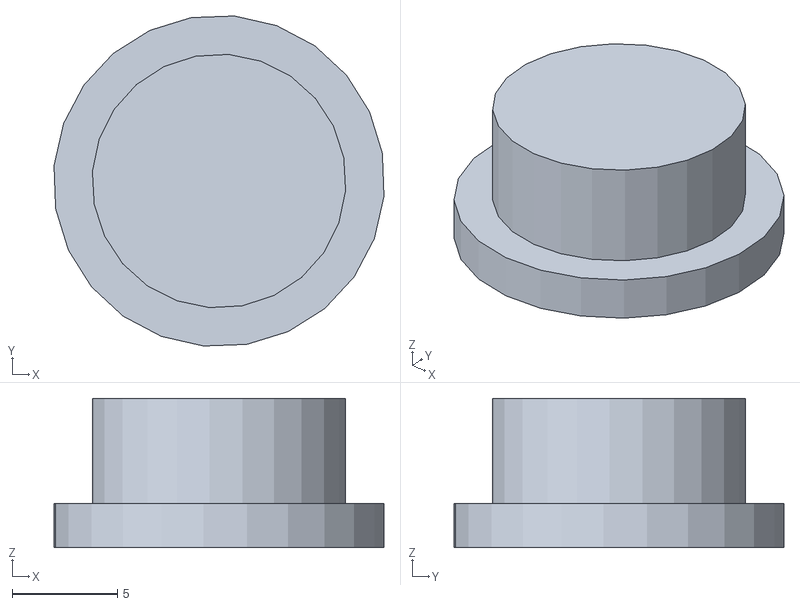
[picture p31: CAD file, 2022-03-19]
3D/KTS_12mm_cark_slim.stl
15.7 x 15.7 x 7.09

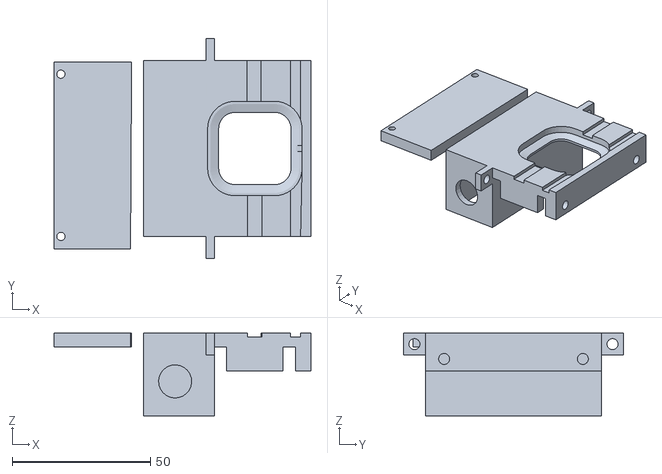
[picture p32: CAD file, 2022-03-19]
3D/KTS_adc_box_case.stl
93.0 x 79.7 x 30.0

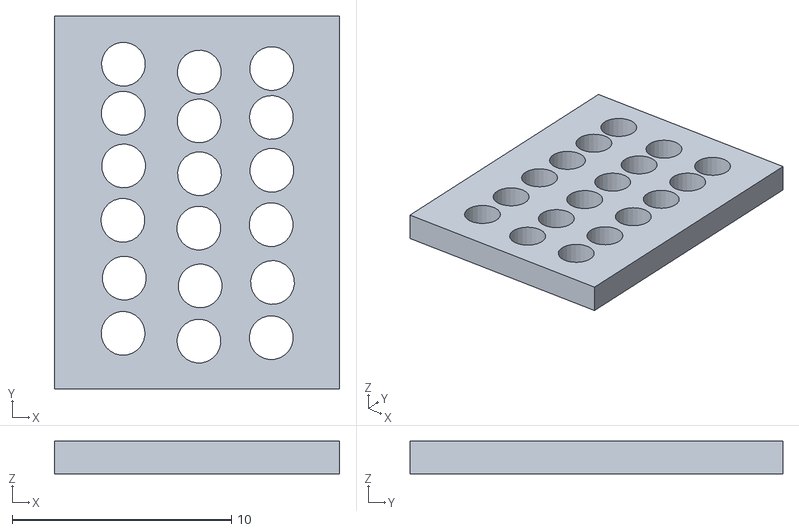
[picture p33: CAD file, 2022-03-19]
3D/KTS_temp_case_tap.stl
13.0 x 17.0 x 1.50

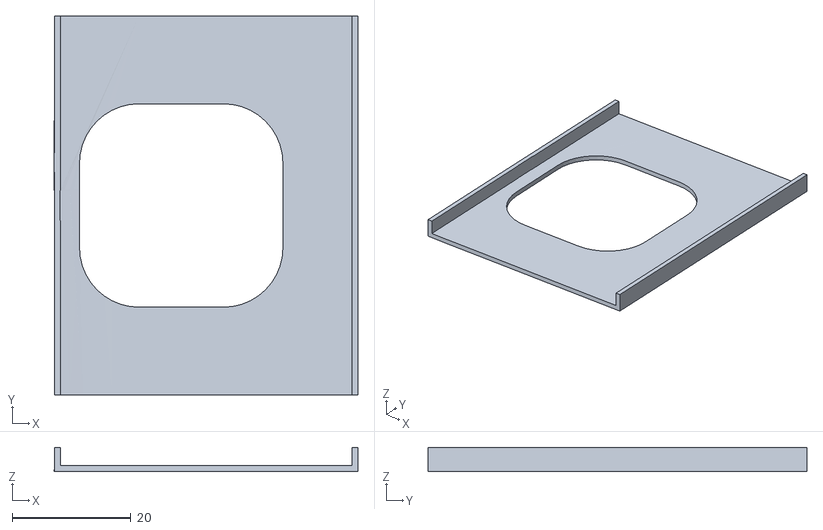
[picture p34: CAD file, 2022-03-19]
3D/KTS_loadcell_cover.stl
51.0 x 63.7 x 4.05

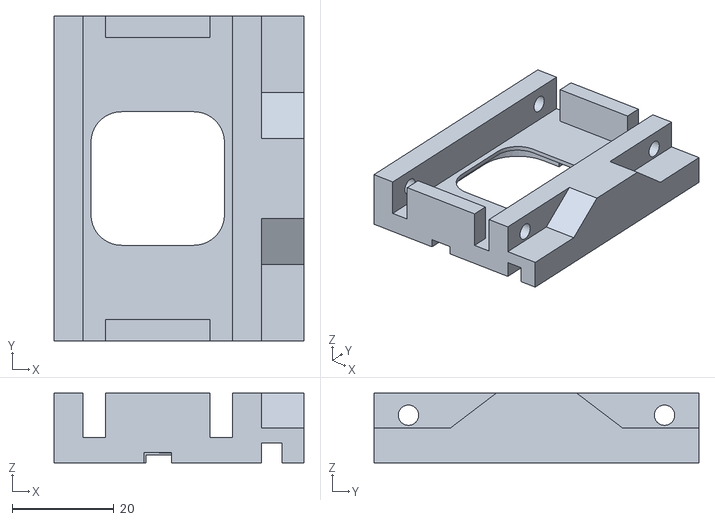
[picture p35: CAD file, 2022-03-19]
3D/KTS_loadcell_case.stl
49.0 x 63.7 x 13.7

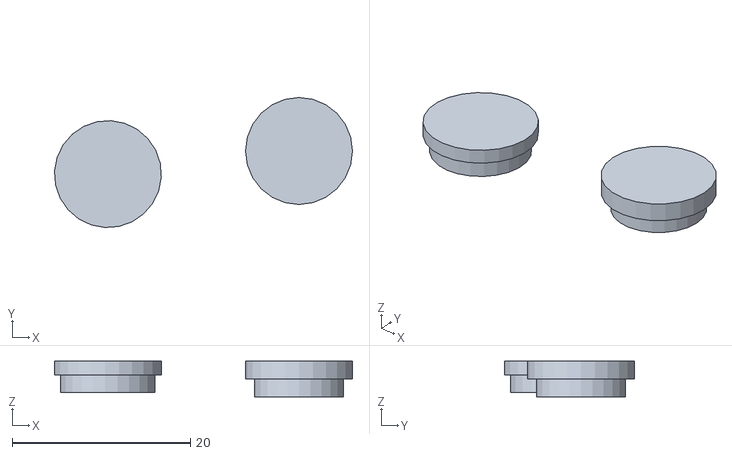
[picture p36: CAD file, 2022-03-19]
3D/KTS_12mm_cork.stl
33.4 x 14.6 x 4.00

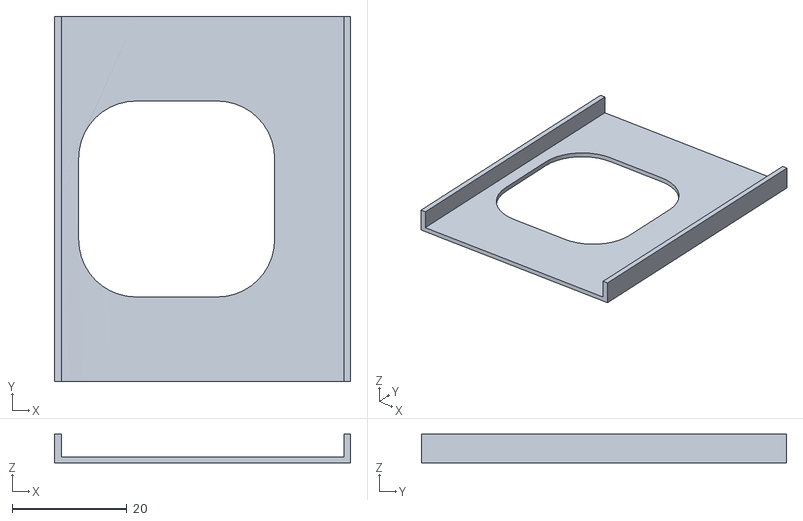
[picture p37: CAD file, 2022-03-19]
3D/KTS_loadcell_cover_longarm.stl
51.7 x 63.7 x 5.05

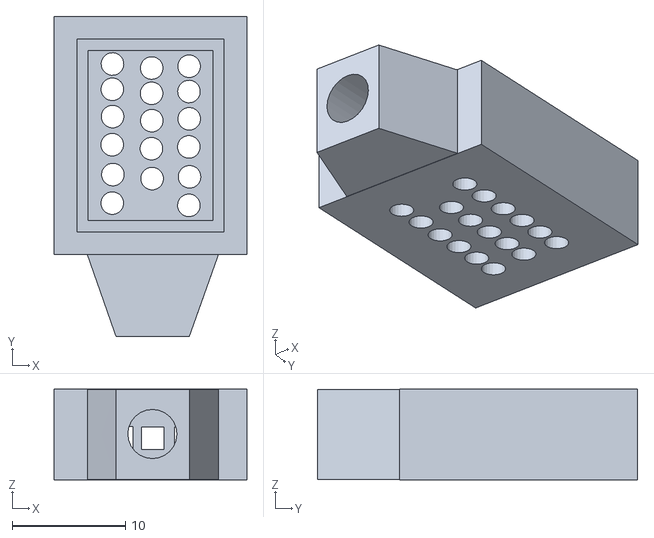
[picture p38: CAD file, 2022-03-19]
3D/KTS_temp_case.stl
17.0 x 28.2 x 8.00

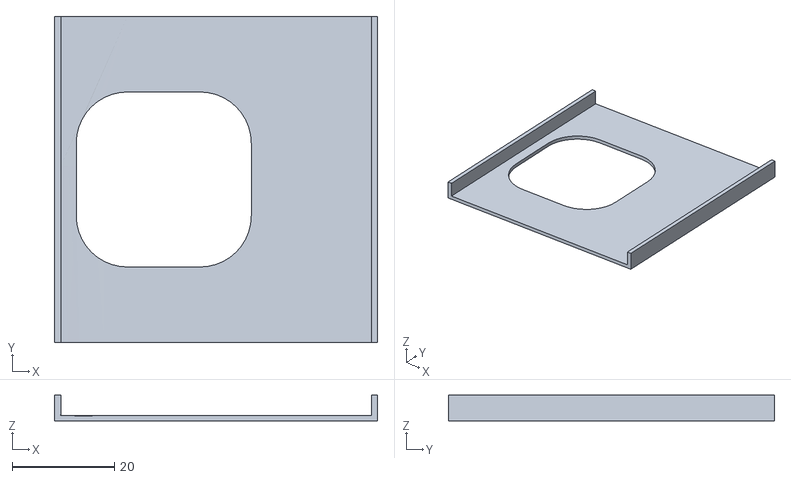
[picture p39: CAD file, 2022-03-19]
3D/KTS_adc_box_cover.stl
63.1 x 63.7 x 5.05

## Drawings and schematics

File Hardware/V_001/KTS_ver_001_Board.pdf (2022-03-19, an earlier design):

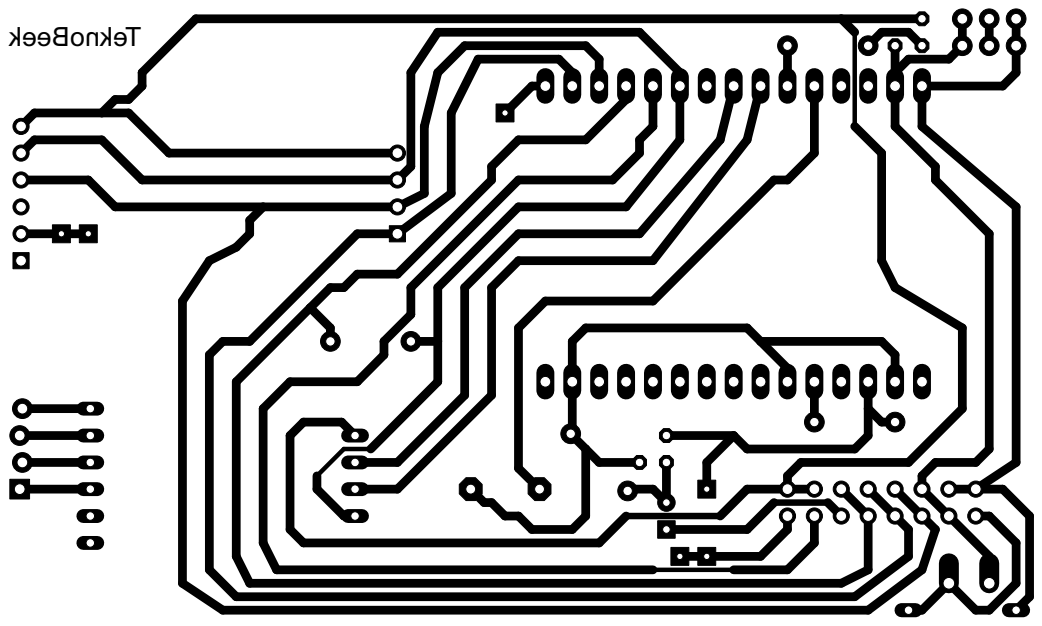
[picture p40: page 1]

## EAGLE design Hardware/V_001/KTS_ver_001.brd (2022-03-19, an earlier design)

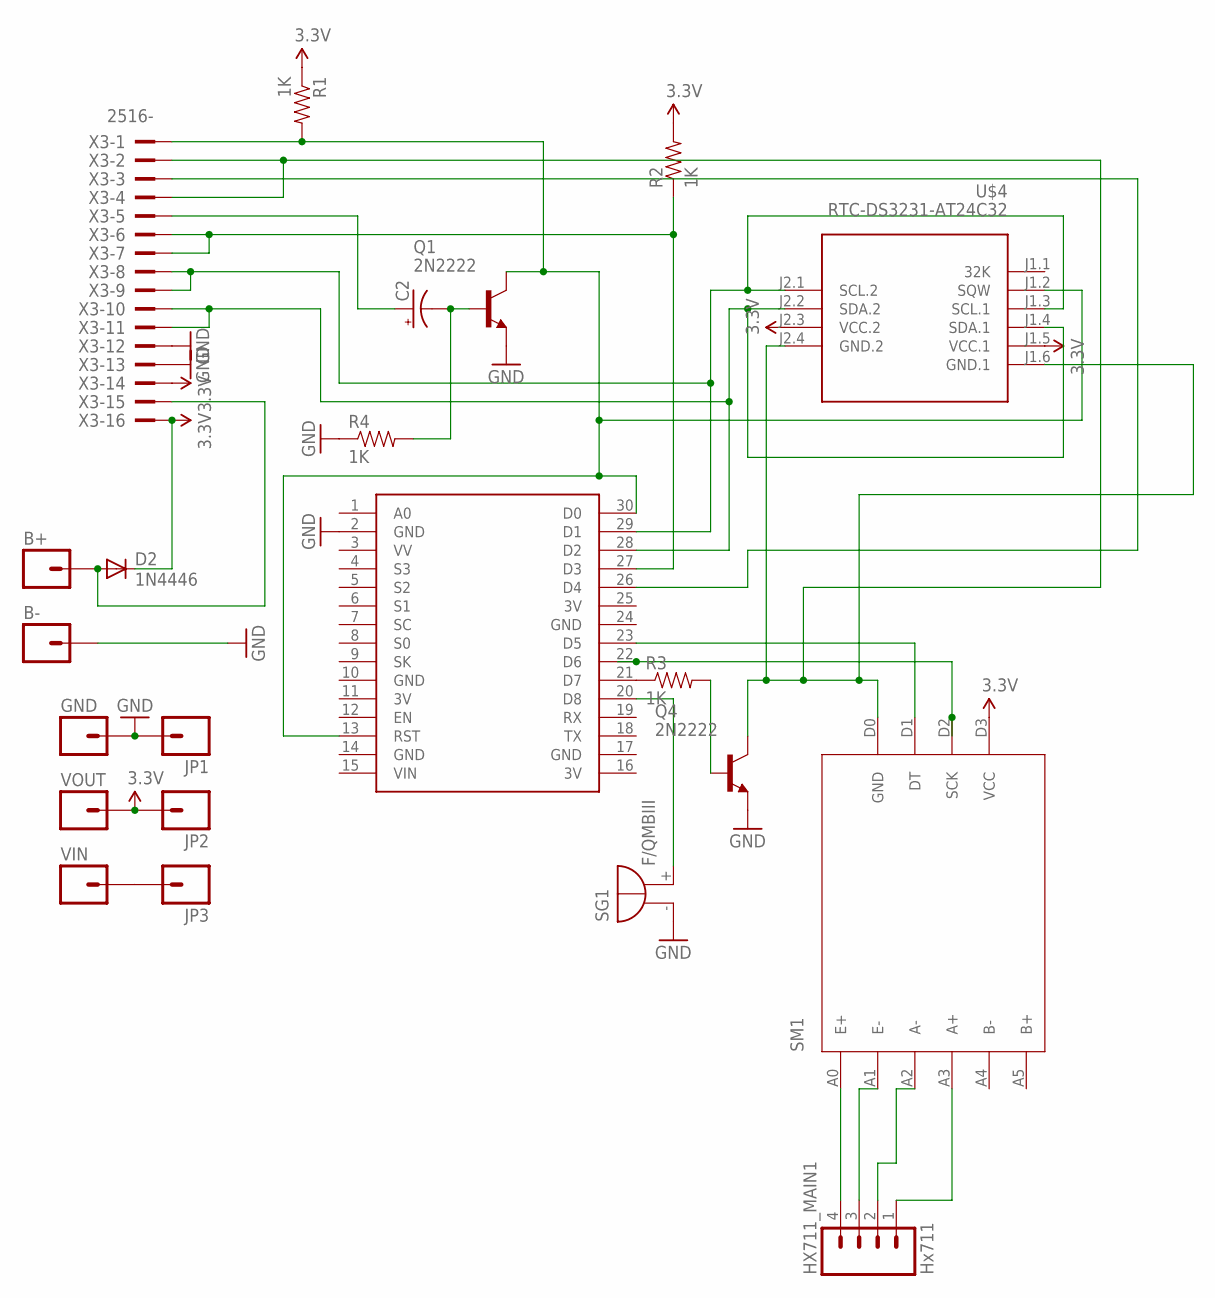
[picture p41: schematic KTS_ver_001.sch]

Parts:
B+: M01OFFSET; 1X01_OFFSET
B-: M01OFFSET; 1X01_OFFSET
C2: CAP_POLPTH2; CPOL-RADIAL-10UF-25V
D2: 1N4446; DO35-10
GND: M01PTH; 1X01
HX711_MAIN1: Hx711; 1X04_LOCK
JP1, JP2, JP3: M01PTH; 1X01
Q1, Q4: 2N2222; TO18
R1, R2, R3, R4: 1K; AXIAL-0.3
SG1: F/QMBIII
SM1: HX711
U$3: NODEMCU
U$4: RTC-DS3231-AT24C32
VIN: M01PTH; 1X01
VOUT: M01PTH; 1X01
X3: 2516-; PAK100/2500-16

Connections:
3.3V: D2.C, JP2.1, R1.P$1 (1), R2.P$2 (2), SM1.D3 (VCC), U$4.J1.5 (VCC.1), U$4.J2.3 (VCC.2), VOUT.1, X3.14, X3.16
3V: U$3.11 (3V), U$3.16 (3V), U$3.25 (3V)
BUTTON/D1: U$3.26 (D4), X3.3
D7: R3.P$1 (1), U$3.21 (D7)
D8/BUZZER1: SG1.+ (-), U$3.20 (D8)
DS18B20/D1: R2.P$1 (1), U$3.27 (D3), X3.6, X3.7
GND: B-.1, GND.1, JP1.1, Q1.1 (E), Q4.1 (E), R4.P$1 (1), SG1.- (+), U$3.2 (GND), U$3.10 (GND), U$3.14 (GND), U$3.17 (GND), U$3.24 (GND), X3.12, X3.13
HX711/DT/D5: SM1.D1 (DT), U$3.23 (D5)
LOADBUS1: Q4.3 (C), SM1.D0 (GND), U$4.J1.6 (GND.1), U$4.J2.4 (GND.2), X3.2, X3.4
unnamed: B+.1, D2.A, X3.15
unnamed: C2.2 (-), Q1.2 (B), R4.P$2 (2)
unnamed: Q4.2 (B), R3.P$2 (2)
unnamed: JP3.1, VIN.1
unnamed: HX711_MAIN1.4, SM1.A0 (E+)
unnamed: HX711_MAIN1.3, SM1.A1 (E-)
unnamed: HX711_MAIN1.2, SM1.A2 (A-)
unnamed: HX711_MAIN1.1, SM1.A3 (A+)
RESET_BUS1: Q1.3 (C), R1.P$2 (2), U$3.13 (RST), U$3.30 (D0), U$4.J1.2 (SQW), X3.1
SCK/D6/HX711: SM1.D2 (SCK), U$3.22 (D6)
SCL/D2: U$3.29 (D1), U$4.J1.3 (SCL.1), U$4.J2.1 (SCL.2), X3.8, X3.9
SDA/D1: U$3.28 (D2), U$4.J1.4 (SDA.1), U$4.J2.2 (SDA.2), X3.10, X3.11
SIGNAL(RESET): C2.1 (+), X3.5

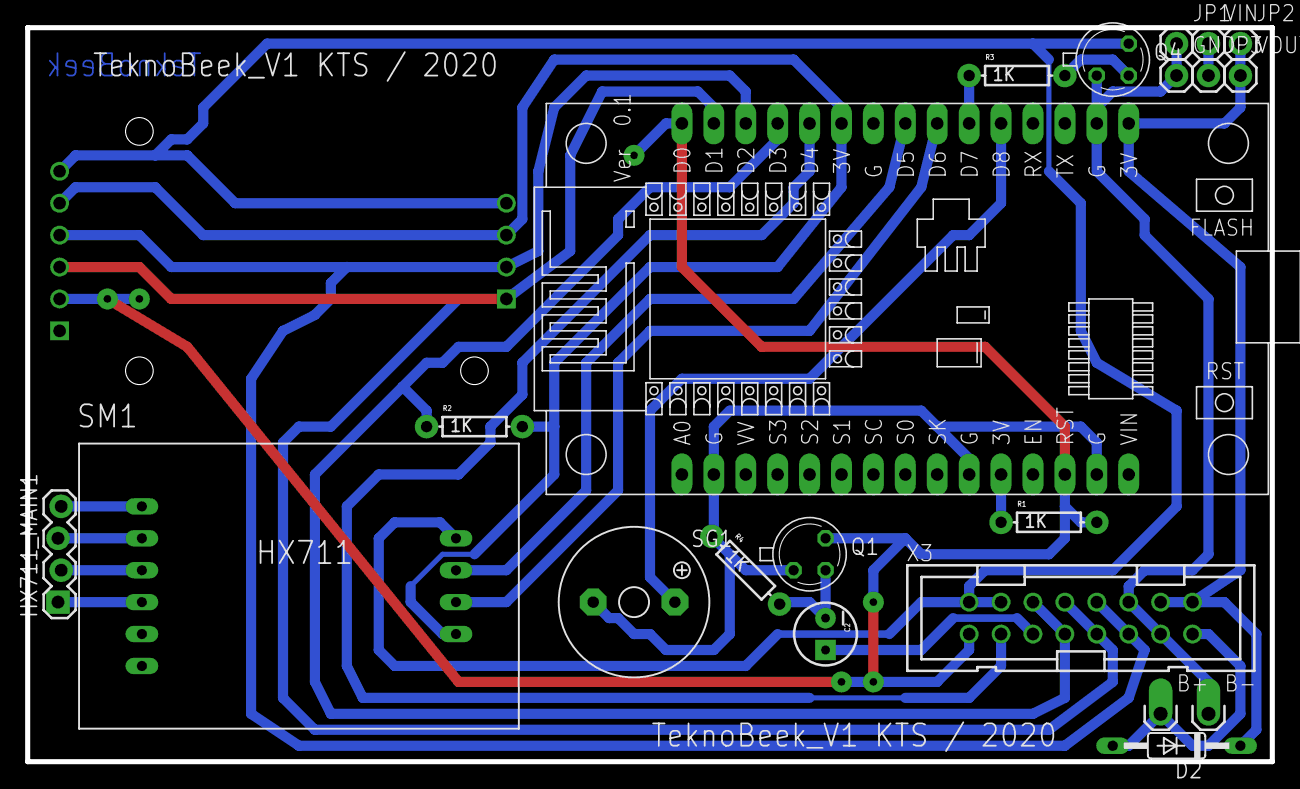
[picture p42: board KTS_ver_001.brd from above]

Board: 2 copper layers, 99.1 x 58.4 mm, 22 parts (1 on the bottom side), 22 nets.

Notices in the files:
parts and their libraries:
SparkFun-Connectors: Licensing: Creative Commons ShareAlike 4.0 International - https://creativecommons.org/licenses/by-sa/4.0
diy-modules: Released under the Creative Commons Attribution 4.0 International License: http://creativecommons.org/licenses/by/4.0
